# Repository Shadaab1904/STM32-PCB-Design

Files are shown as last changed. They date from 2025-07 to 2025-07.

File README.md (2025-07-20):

# STM32-PCB-Design
KiCad project:  STM32 PCB Design on STM32F103C8T6

# About
This repository contains the KiCad 9.0 schematic for a custom-designed STM32-based development board. The board is built around the **STM32F103C8T6** microcontroller and provides core functionalities such as USB power, external clocking, GPIO headers, voltage regulation, and indicator LEDs ideal for prototyping, embedded systems development.

It includes: 

- STM32F103C8T6:  ARM Cortex-M3 microcontroller (Blue Pill)     
- USB_B_Micro: USB Micro-B connector for programming/power    
- AMS1117-3.3: Voltage regulator (3.3V output)                
- Crystal: External crystal oscillator with GND pads     
- FB: FerriteBead: Noise filter on power rail
- LED: Status or debug indicator
- Resistor: For LED and pull-up/down functions
- Capacitor: Decoupling and oscillator loading
- Conn_01x04_Pin: 4-pin GPIO header                            
- MountingHoles: Mechanical support for enclosure/PCB mount   

## 📂 Project structure
- `My_STM32_Board.kicad_sch` – Schematic file
- `My_STM32_Board_pcb` – PCB layout file
- `My_STM32_Board_pro` – KiCad project file
- `gerber/` – Gerber and drill files for fabrication
- `bom.csv` – Bill of Materials

- ## ⚙️ Tools
- Designed with [KiCad](https://kicad.org/)

- ## Features
  
- **Input**: USB Micro-B (5V)
- **Regulation**: 5V to 3.3V via **AMS1117-3.3** LDO regulator
- **Noise Filtering**: Ferrite bead between 3.3V rail and microcontroller

  Clock Circuit:

- Onboard Crystal oscillator provides accurate timing
- Crystal is connected to STM32’s OSC_IN/OSC_OUT with matching capacitors

  I/O and Connectivity:

- **USB Connector** allows firmware upload and power
- **4-pin GPIO Header** for serial comms, I2C/SPI, or digital I/O
- **LED Indicator** for debug or power status
- 

- ## 📦 Fabrication
Use the files in the `gerber/` directory to order PCBs from manufacturers (e.g., JLCPCB etc.).

- ## 📄 License
MIT License – feel free to modify and use.

## 🙌 Contributions
Pull requests welcome! If you spot issues or have improvements, please open an issue or PR.

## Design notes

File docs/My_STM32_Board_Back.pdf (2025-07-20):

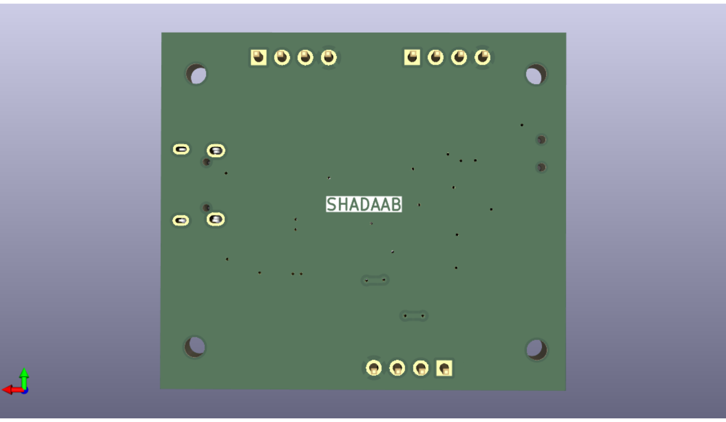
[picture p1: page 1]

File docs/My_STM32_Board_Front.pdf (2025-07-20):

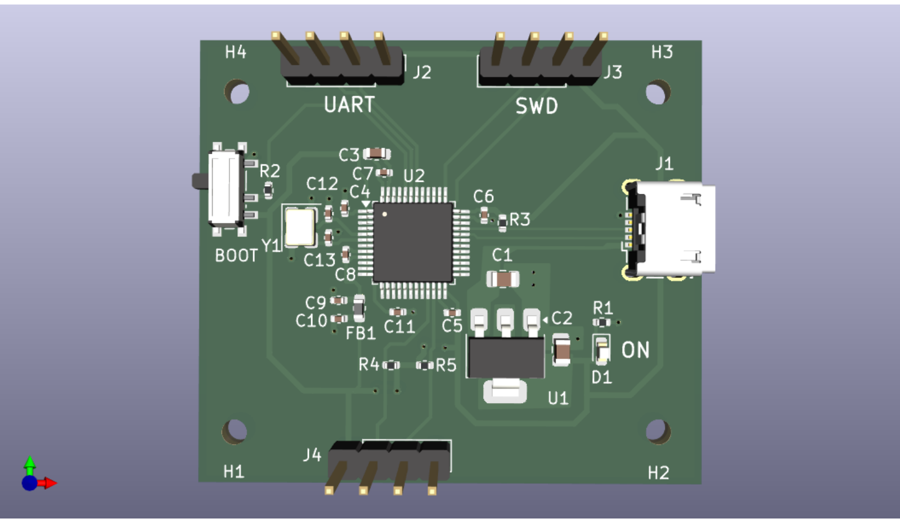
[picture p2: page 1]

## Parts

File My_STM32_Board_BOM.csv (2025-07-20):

Reference | Qty | Value | DNP | Exclude from BOM | Exclude from Board | Footprint | Datasheet
C1,C2 | 2 | 22u |  |  |  | Capacitor_SMD:C_0805_2012Metric | ~
C3 | 1 | 10u |  |  |  | Capacitor_SMD:C_0603_1608Metric | ~
C4,C5,C6,C7,C11 | 5 | 100n |  |  |  | Capacitor_SMD:C_0402_1005Metric | ~
C8 | 1 | 10n |  |  |  | Capacitor_SMD:C_0402_1005Metric | ~
C9,C10 | 2 | 1u |  |  |  | Capacitor_SMD:C_0402_1005Metric | ~
C12,C13 | 2 | 10p |  |  |  | Capacitor_SMD:C_0402_1005Metric | ~
D1 | 1 | RED |  |  |  | LED_SMD:LED_0603_1608Metric | ~
FB1 | 1 | 120R |  |  |  | Inductor_SMD:L_0603_1608Metric | ~
H1,H2,H3,H4 | 4 | MountingHole |  | Excluded from BOM |  | MountingHole:MountingHole_2.2mm_M2 | ~
J1 | 1 | USB_B_Micro |  |  |  | Connector_USB:USB_Micro-B_Wuerth_629105150521 | ~
J2,J3,J4 | 3 | Conn_01x04_Pin |  |  |  | Connector_PinHeader_2.54mm:PinHeader_1x04_P2.54mm_Vertical | ~
R1,R3,R4,R5 | 4 | 1K5 |  |  |  | Resistor_SMD:R_0402_1005Metric | ~
R2 | 1 | 10K |  |  |  | Resistor_SMD:R_0402_1005Metric | ~
SW1 | 1 | SW_SPDT |  |  |  | Button_Switch_SMD:SW_SPDT_PCM12 | ~
U1 | 1 | AMS1117-3.3 |  |  |  | Package_TO_SOT_SMD:SOT-223-3_TabPin2 | http://www.advanced-monolithic.com/pdf/ds1117.pdf
U2 | 1 | STM32F103C8T6 |  |  |  | Package_QFP:LQFP-48_7x7mm_P0.5mm | https://www.st.com/resource/en/datasheet/stm32f103c8.pdf
Y1 | 1 | 16MHZ |  |  |  | Crystal:Crystal_SMD_3225-4Pin_3.2x2.5mm | ~

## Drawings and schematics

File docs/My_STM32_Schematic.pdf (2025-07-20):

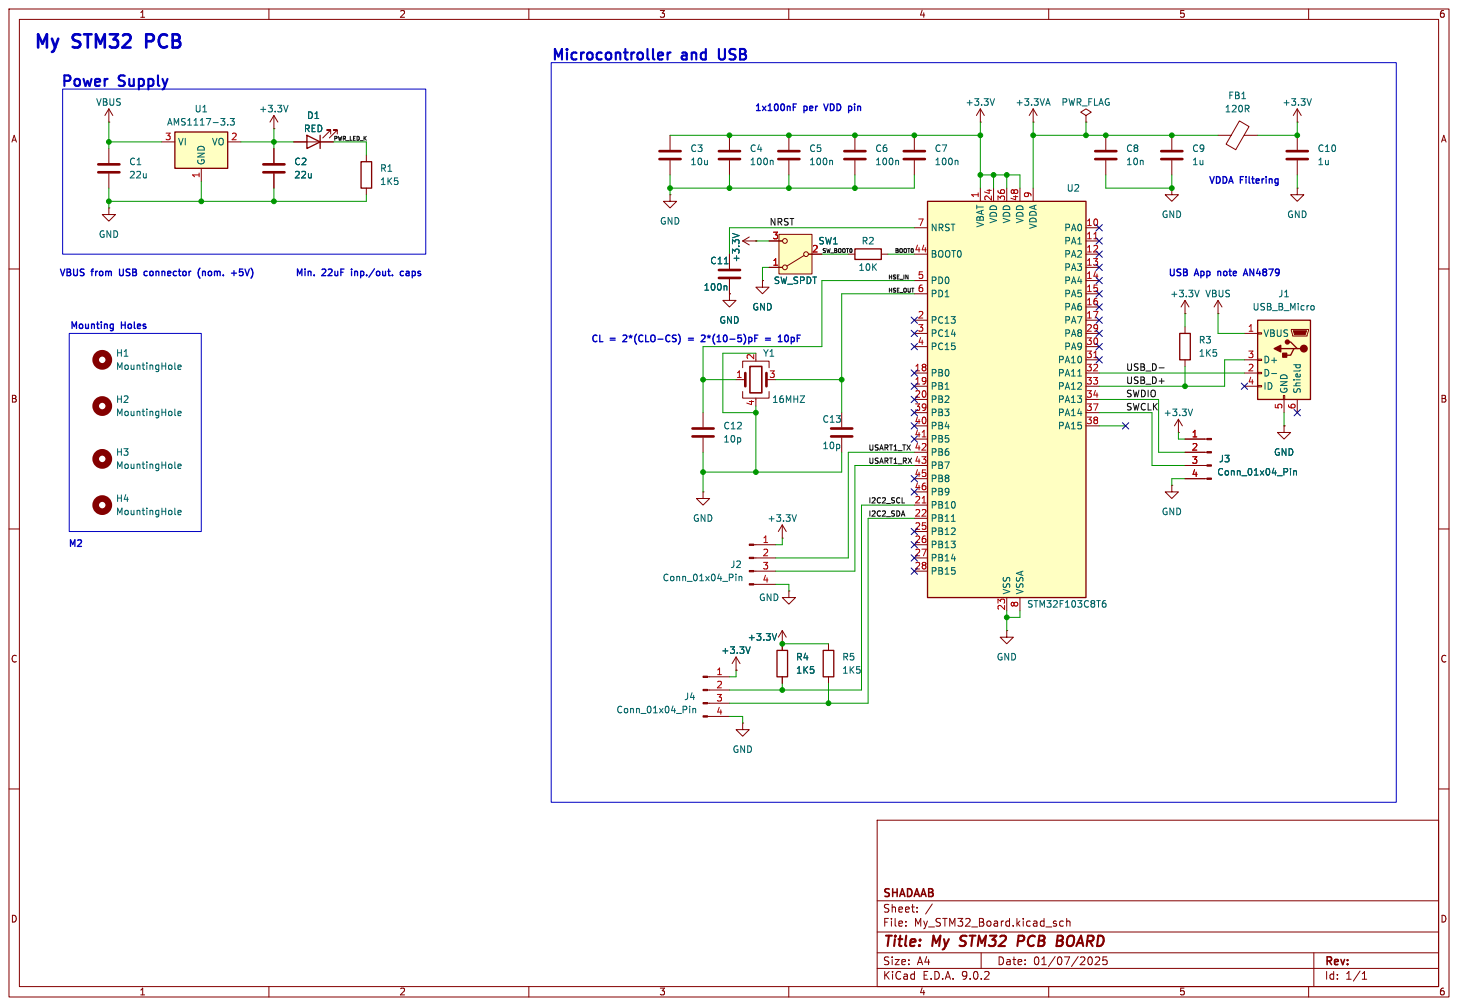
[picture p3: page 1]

1 VO 2 U1 AMS1117-3.3 VBUS GND GND

1 VDD 24 VDD 36 VSS 23 VDD 48 VSSA

Id: 1/1 Title: My STM32 PCB BOARD

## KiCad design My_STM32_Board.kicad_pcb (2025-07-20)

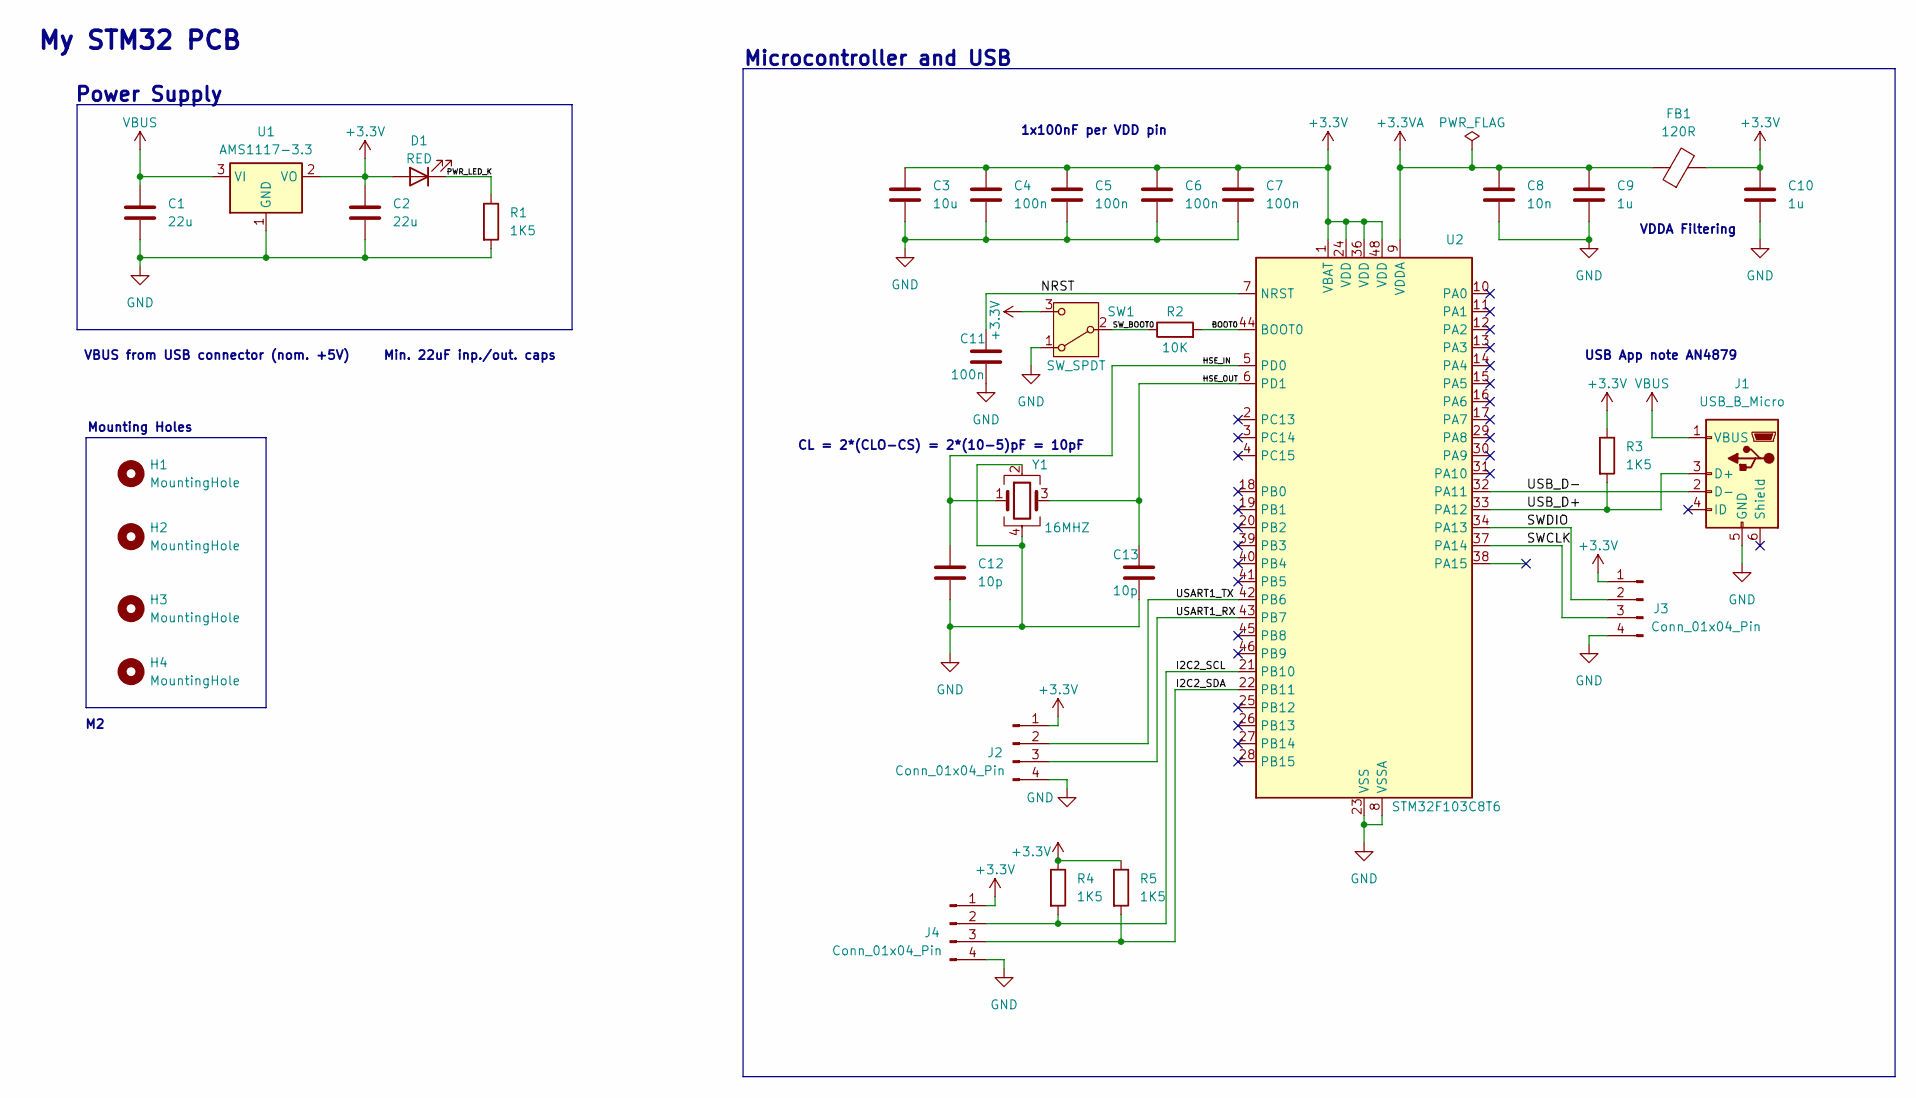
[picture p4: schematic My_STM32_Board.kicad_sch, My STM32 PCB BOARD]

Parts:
C1, C2: 22u; C_0805_2012Metric
C3: 10u; C_0603_1608Metric
C4, C5, C6, C7, C11: 100n; C_0402_1005Metric
C8: 10n; C_0402_1005Metric
C9, C10: 1u; C_0402_1005Metric
C12, C13: 10p; C_0402_1005Metric
D1: RED; LED_0603_1608Metric
FB1: 120R; L_0603_1608Metric
H1, H2, H3, H4: MountingHole; MountingHole_2.2mm_M2
J1: USB_B_Micro; USB_Micro-B_Wuerth_629105150521
J2, J3, J4: Conn_01x04_Pin; PinHeader_1x04_P2.54mm_Vertical
R1, R3, R4, R5: 1K5; R_0402_1005Metric
R2: 10K; R_0402_1005Metric
SW1: SW_SPDT; SW_SPDT_PCM12
U1: AMS1117-3.3; SOT-223-3_TabPin2
U2: STM32F103C8T6; LQFP-48_7x7mm_P0.5mm
Y1: 16MHZ; Crystal_SMD_3225-4Pin_3.2x2.5mm

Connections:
+3.3V: C2.1, C3.1, C4.1, C5.1, C6.1, C7.1, C10.1, D1.2 (A), FB1.2, J2.1, J3.1, J4.1, R3.1, R4.1, R5.1, SW1.3 (C), U1.2 (VO), U2.1 (VBAT), U2.24 (VDD), U2.36 (VDD), U2.48 (VDD); also elsewhere on the board
+3.3VA: C8.1, C9.1, FB1.1, U2.9 (VDDA)
/BOOT0: R2.2, U2.44 (BOOT0)
/HSE_IN: C12.1, U2.5 (PD0), Y1.1
/HSE_OUT: C13.1, U2.6 (PD1), Y1.3
/I2C2_SCL: J4.2, R4.2, U2.21 (PB10)
/I2C2_SDA: J4.3, R5.2, U2.22 (PB11)
/NRST: C11.1, U2.7 (NRST)
/PWR_LED_K: D1.1 (K), R1.1
/SWCLK: J3.3, U2.37 (PA14)
/SWDIO: J3.2, U2.34 (PA13)
/SW_BOOT0: R2.1, SW1.2 (B); also elsewhere on the board
/USART1_RX: J2.3, U2.43 (PB7)
/USART1_TX: J2.2, U2.42 (PB6)
/USB_D+: J1.3 (D+), R3.2, U2.33 (PA12)
/USB_D-: J1.2 (D-), U2.32 (PA11)
GND: C1.2, C2.2, C3.2, C4.2, C5.2, C6.2, C7.2, C8.2, C9.2, C10.2, C11.2, C12.2, C13.2, J1.5 (GND), J2.4, J3.4, J4.4, R1.2, SW1.1 (A), U1.1 (GND), U2.8 (VSSA), U2.23 (VSS), U2.35 (VSS), U2.47 (VSS), Y1.2, Y1.4; also elsewhere on the board
VBUS: C1.1, J1.1 (VBUS), U1.3 (VI)

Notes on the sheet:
Power Supply
1x100nF per VDD pin
Microcontroller and USB
USB App note AN4879
VDDA Filtering
VBUS from USB connector (nom. +5V) Min. 22uF inp./out. caps
Mounting Holes
My STM32 PCB
CL = 2*(CLO-CS) = 2*(10-5)pF = 10pF

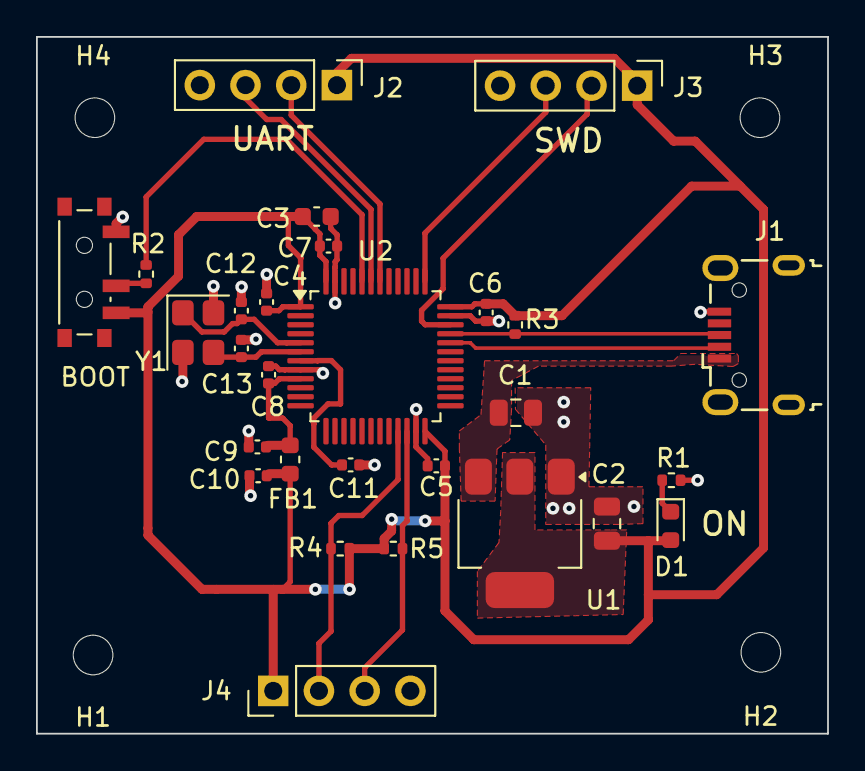
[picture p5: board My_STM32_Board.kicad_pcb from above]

Board: 2 copper layers, 44.0 x 38.7 mm, 32 parts (0 on the bottom side), 18 nets.

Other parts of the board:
BOOT: SW_SPDT; SW_SPDT_PCM12

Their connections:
+3.3V: BOOT.3 (C); also elsewhere on the board
/SW_BOOT0: BOOT.2 (B); also elsewhere on the board
GND: BOOT.1 (A); also elsewhere on the board
